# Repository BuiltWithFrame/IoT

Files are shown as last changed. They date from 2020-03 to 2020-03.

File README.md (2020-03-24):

# 👋 This is the Frame.IoT
The Frame.IoT is an Arduino-compatible board built for your Internet of Things projects and ships with the most popular components built-in — voted by the community. Now you can focus on building something awesome (instead of wiring up the basics).
# 💪 Everything you need
Powered by the ESP-32, the Frame.IoT is Wi-Fi and Bluetooth Low Energy (BLE) enabled. We packed it with all the plug-and-play utilities you've come to expect — USB-to-Serial converter, automatic bootloader reset and Lithium Ion/Polymer battery charging circuit. To make it project-ready, we gave the Frame.IoT a microSD card socket for all your data logging/storage needs, a super powerful digital audio amp to stream audio over the internet and blast notifications, a 16-pixel addressable RGB LED ring to light up your project, a toggle that lets you choose to power your peripherals over USB or battery, and an unencumbered momentary push-button to trigger any action you choose.
# 🙅‍♂️ No wasted pins
Not all projects are created equal. If your prototype doesn't need some of the components built-in to the Frame.IoT — no worries! Each component is connected via jumper pins. Simply remove the corresponding jumpers and you'll free up the I/O for anything you want!
# 🎗 The people who made this possible
This board was crowd-crafted and is in the process of being crowdfunded. [Click here to learn more, contribute, and get your name listed here.](https://www.kickstarter.com/projects/builtwithframe/frameiot-an-arduino-compatible-dev-kit-for-wi-fi-projects)
# ⚡️ Pinout
Frame.IoT Pinout

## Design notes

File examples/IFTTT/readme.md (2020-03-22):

# An Internet of Buttons
One of the most versatile uses of the Frame.IoT is leveraging the perfectly-positioned pushbutton (on digital pin 16) to trigger action in the world through platforms like IFTTT, Zapier, or your own native integrations with home automation platforms like Google Home, Apple Homekit, and Alexa.

Connect even the furriest of things to the internet

In this example, we're saving a lot of the coding headache by simply sending a `POST` request to an existing endpoint in IFTTT. IFTTT handles the rest and triggers a push notification to the registered device with the IFTTT app installed.

### Steps to recreate:
1. Fork/download the above `IFTTT.ino` sketch. Make sure you have all the libraries that are included or else the sketch won't compile
2. Change the `ssid` and `password` variables to match your network. (You can build upon this sketch to add your own networking handling and captive portals.)
3. Download the IFTTT mobile app for iOS/Android and create/login to a free account.
4. Create a new Applet and configure the trigger to be a Webhook. Note your `Event Name` and your `key`.
5. Going back to the sketch, replace the following line with your endpoint: `http.begin("https://maker.ifttt.com/trigger/{your_action}/with/key/{your_key}");`. It's safe to compile and upload this sketch to your Frame.IoT now.
6. In IFTTT, add an action step. We used the built-in notification system to trigger an alert but the possibilities are endless. You could even pass sensor data into the HTTP POST request and leverage the data on the action side.

Happy making!

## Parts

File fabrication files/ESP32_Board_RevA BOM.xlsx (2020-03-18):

ESP32_Board_RevA BOM | Created By: Junaid www.fiverr.com/junaid_ahmad92
Serial Number | Manufacturer | Manufacturer Part Number | Ref Designator | Qty | Description | Case | SMD, BGA, LCC (QFN) or TH | Top/ Bottom | Comments | Price/unint | Price/board | Internet Link
1 | Wurth Electronics Inc. | 61300211121 | J1, J2, J3, J4, J5, J6, J7, J8, J9, J10, J11, J12, J13 | 13 | CONN HEADER VERT 2POS 2.54MM |  |  |  |  | $0.13 | $1.69 | https://www.digikey.com/product-detail/en/wurth-electronics-inc/61300211121/732-5315-ND/4846823
2 | Harwin Inc. | M20-9991245 | J15 | 1 | CONN HEADER VERT 12POS 2.54MM |  |  |  |  | $0.46 | $0.46 | https://www.digikey.com/product-detail/en/harwin-inc/M20-9991245/952-3302-ND/3921252
3 | Harwin Inc. | M20-9991645 | J16 | 1 | CONN HEADER VERT 16POS 2.54MM |  |  |  |  | $0.60 | $0.60 | https://www.digikey.com/product-detail/en/harwin-inc/M20-9991645/952-3304-ND/3921260
4 | Phoenix Contact | 1984617 | SPKR1 | 1 | TERM BLK 2POS SIDE ENT 3.5MM PCB |  |  |  |  | $0.48 | $0.48 | https://www.digikey.com/product-detail/en/phoenix-contact/1984617/277-1721-ND/950849
5 | Samsung Electro-Mechanics | CL10B104KB8NNNC | C5, C10, C14, C15, C16, C17, C18 | 7 | CAP CER 0.1UF 50V X7R 0603 |  |  |  |  | $0.10 | $0.70 | https://www.digikey.com/product-detail/en/samsung-electro-mechanics/CL10B104KB8NNNC/1276-1000-1-ND/3889086
6 | Yageo | RC0603FR-07100KL | R1, R3, R7, R12, R9 | 5 | RES SMD 100K OHM 1% 1/10W 0603 |  |  |  |  | $0.10 | $0.50 | https://www.digikey.com/product-detail/en/yageo/RC0603FR-07100KL/311-100KHRCT-ND/729836
7 | Amphenol ICC (FCI) | 10118194-0001LF | J14 | 1 | CONN RCPT USB2.0 MICRO B SMD R/A |  |  |  |  | $0.42 | $0.70 | https://www.digikey.com/product-detail/en/amphenol-icc-fci/10118194-0001LF/609-4618-1-ND/2785382
8 | Yageo | YC164-JR-0710KL | R13 | 1 | RES ARRAY 4 RES 10K OHM 1206 |  |  |  |  | $0.11 | $0.11 | https://www.digikey.com/product-detail/en/yageo/YC164-JR-0710KL/YC164J-10KCT-ND/1005702
9 | KEMET | C0805C106K8PACTU | C1, C2, C3, C6, C8 | 5 | CAP CER 10UF 10V X5R 0805 |  |  |  |  | $0.16 | $0.80 | https://www.digikey.com/product-detail/en/kemet/C0805C106K8PACTU/399-4925-1-ND/1090920
10 | Yageo | RC0603FR-071KL | R2, R5 | 2 | RES SMD 1K OHM 1% 1/10W 0603 |  |  |  |  | $0.10 | $0.20 | https://www.digikey.com/product-detail/en/yageo/RC0603FR-071KL/311-1.00KHRCT-ND/729790
11 | Yageo | RC0603FR-071ML | R6 | 1 | RES SMD 1M OHM 1% 1/10W 0603 |  |  |  |  | $0.10 | $0.10 | https://www.digikey.com/product-detail/en/yageo/RC0603FR-071ML/311-1.00MHRCT-ND/729791
12 | Samsung Electro-Mechanics | CL10A105KA8NNNC | C4, C7 | 2 | CAP CER 1UF 25V X5R 0603 |  |  |  |  | $0.10 | $0.20 | https://www.digikey.com/product-detail/en/samsung-electro-mechanics/CL10A105KA8NNNC/1276-1102-1-ND/3889188
13 | Samsung Electro-Mechanics | CL10B221KB8NNNC | C12, C13 | 2 | CAP CER 220PF 50V X7R 0603 |  |  |  |  | $0.10 | $0.20 | https://www.digikey.com/product-detail/en/samsung-electro-mechanics/CL10B221KB8NNNC/1276-1145-1-ND/3889231
14 | Yageo | RC0603FR-074K7L | R4 | 1 | RES SMD 4.7K OHM 1% 1/10W 0603 |  |  |  |  | $0.10 | $0.10 | https://www.digikey.com/product-detail/en/yageo/RC0603FR-074K7L/311-4.70KHRCT-ND/730159
15 | Nexperia USA Inc. | 74HC4050D,653 | IC2 | 1 | IC BUFFER NON-INVERT 6V 16SO |  |  |  |  | $0.44 | $0.44 | https://www.digikey.com/product-detail/en/nexperia-usa-inc/74HC4050D653/1727-6331-1-ND/2762840
16 | Yageo | RC0603FR-07470RL | R8 | 1 | RES SMD 470 OHM 1% 1/10W 0603 |  |  |  |  | $0.10 | $0.10 | https://www.digikey.com/product-detail/en/yageo/RC0603FR-07470RL/311-470HRCT-ND/730203
17 | Diodes Incorporated | AP2112K-3.3TRG1 | U2 | 1 | IC REG LINEAR 3.3V 600MA SOT25 |  |  |  |  | $0.49 | $0.49 | https://www.digikey.com/product-detail/en/diodes-incorporated/AP2112K-3.3TRG1/AP2112K-3.3TRG1DICT-ND/4505257
18 | Silicon Labs | CP2104-F03-GMR | IC1 | 1 | IC SGL USB-TO-UART BRIDGE 24QFN |  |  |  |  | $1.65 | $1.65 | https://www.digikey.com/product-detail/en/silicon-labs/CP2104-F03-GMR/336-4146-1-ND/7650425
19 | Diodes Incorporated | DMG3415U-7 | Q3 | 1 | MOSFET P-CH 20V 4A SOT-23 |  |  |  |  | $0.42 | $0.42 | https://www.digikey.com/product-detail/en/diodes-incorporated/DMG3415U-7/DMG3415UDICT-ND/2052799
20 | E-Switch | EG1213 | S1 | 1 | SWITCH SLIDE SPDT 200MA 30V |  |  |  |  | $0.60 | $0.60 | https://www.digikey.com/products/en?keywords=EG1213
21 | Espressif Systems | ESP32-WROOM-32 | X5 | 1 | SMD MODULE, ESP32-D0WDQ6, 32MBIT |  |  |  |  | $3.80 | $3.80 | https://www.digikey.com/product-detail/en/espressif-systems/ESP32-WROOM-32/1904-1010-1-ND/8544305
22 | Taiyo Yuden | BKP2125HS600-T | FB1, FB2 | 2 | FERRITE BEAD 60 OHM 0805 1LN |  |  |  |  | $0.10 | $0.20 | https://www.digikey.com/product-detail/en/taiyo-yuden/BKP2125HS600-T/587-1932-6-ND/1465549
23 | JST Sales America Inc. | S2B-PH-SM4-TB(LF)(SN) | X2 | 1 | CONN HEADER SMD R/A 2POS 2MM |  |  |  |  | $0.58 | $0.58 | https://www.digikey.com/product-detail/en/jst-sales-america-inc/S2B-PH-SM4-TB-LF-SN/455-1749-1-ND/926846
24 | C&K | KMR231NG LFS | SW2 | 1 | SWITCH TACTILE SPST-NO 0.05A 32V |  |  |  |  | $0.52 | $0.52 | https://www.digikey.com/product-detail/en/c-k/KMR231NG-LFS/CKN10246CT-ND/2176497
25 | Maxim Integrated | MAX98357AETE+T | U1 | 1 | IC AMP CLASS D MONO 3.2W 16TQFN |  |  |  |  | $2.40 | $2.40 | https://www.digikey.com/product-detail/en/maxim-integrated/MAX98357AETE-T/MAX98357AETE-TCT-ND/7603777
26 | ON Semiconductor | MBR120VLSFT1G | D4 | 1 | DIODE SCHOTTKY 20V 1A SOD123FL |  |  |  |  | $0.45 | $0.45 | https://www.digikey.com/product-detail/en/on-semiconductor/MBR120VLSFT1G/MBR120VLSFT1GOSCT-ND/893874
27 | Microchip Technology | MCP73831T-2ACI/OT | U3 | 1 | IC CONTROLLR LI-ION 4.2V SOT23-5 |  |  |  |  | $0.56 | $0.56 | https://www.digikey.com/product-detail/en/microchip-technology/MCP73831T-2ACI-OT/MCP73831T-2ACI-OTCT-ND/1979802
28 | Amphenol ICC (Commercial Products) | 114-00841-68 | J17 | 1 | CONN MICRO SD CARD PUSH-PULL R/A |  |  |  |  | $1.13 | $1.13 | https://www.digikey.com/product-detail/en/amphenol-icc-commercial-products/114-00841-68/114-00841-68-1-ND/2187101
29 | C&K | PTS526 SKG15 SMTR2 LFS | S2 | 1 | TACT 5.2 X 5.2, 1.5 MM H, 260GF, |  |  |  |  | $0.10 | $0.10 | https://www.digikey.com/product-detail/en/c-k/PTS526-SKG15-SMTR2-LFS/CKN12223-1-ND/10056636
30 | Lite-On Inc. | LTST-C171KRKT | CHG, ACT | 2 | LED RED CLEAR SMD |  |  |  |  | $0.29 | $0.58 | https://www.digikey.com/product-detail/en/lite-on-inc/LTST-C171KRKT/160-1427-1-ND/386800
31 | Adafruit Industries LLC | 1655 | LED1, LED2, LED3, LED4, LED5, LED6, LED7, LED8, LED9, LED10, LED11, LED12, LED13, LED14, LED15, LED16 | 16 | ADDRESS LED DISC SERIAL RGB 1=10 |  |  |  | SK6812 in 5050 will work too | $0.45 | $7.20 | https://www.digikey.com/product-detail/en/adafruit-industries-llc/1655/1528-1104-ND/5154679
32 | Diodes Incorporated | MMBT2222A-7-F | Q1, Q2 | 2 | TRANS NPN 40V 0.6A SMD SOT23-3 |  |  |  |  | $0.13 | $0.26 | https://www.digikey.com/product-detail/en/diodes-incorporated/MMBT2222A-7-F/MMBT2222A-FDICT-ND/815723

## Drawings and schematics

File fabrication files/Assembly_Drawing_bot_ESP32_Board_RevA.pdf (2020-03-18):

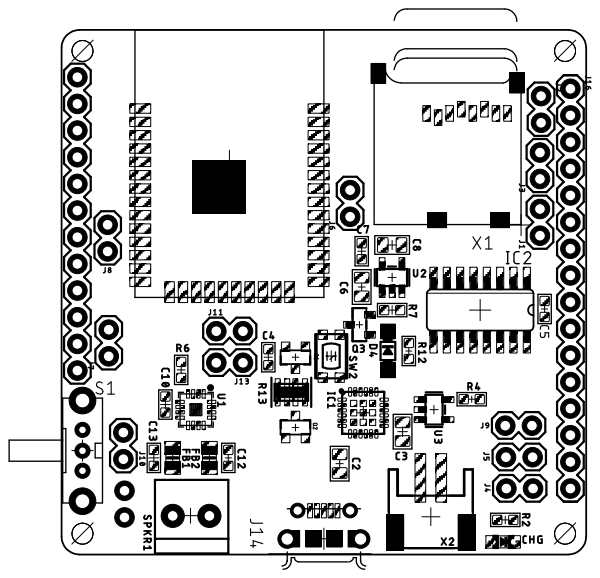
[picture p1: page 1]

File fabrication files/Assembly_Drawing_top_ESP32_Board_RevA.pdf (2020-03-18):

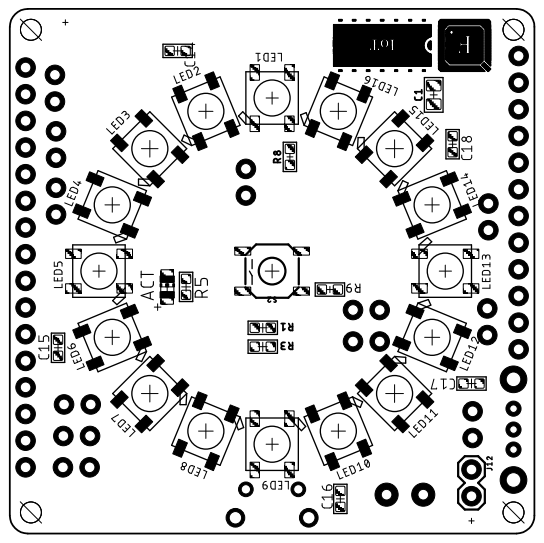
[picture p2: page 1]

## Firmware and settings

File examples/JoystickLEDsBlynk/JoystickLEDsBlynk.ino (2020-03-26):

#include <WiFi.h>
#include <WiFiClient.h>
#include <BlynkSimpleEsp32.h>
#include <NeoPixelBus.h>
#define BLYNK_PRINT Serial

char auth[] = "#########################";
char ssid[] = "########";
char pass[] = "########";
const uint16_t PixelCount = 16;
const uint16_t PixelPin = 32;
int xCenter, yCenter, xReading, yReading, pixelNumber, oldPixelNumber;

NeoPixelBus<NeoGrbFeature, Neo800KbpsMethod> strip(PixelCount, PixelPin);

void setup() {
  xCenter = 512;
  yCenter = 512;
  xReading = 512;
  yReading = 512;
  pixelNumber = -1;
  oldPixelNumber = pixelNumber;
  Serial.begin(115200);
  Blynk.begin(auth, ssid, pass);
  strip.Begin();
  strip.Show();
}

void loop() {
  Blynk.run();
  strip.Show();
}

BLYNK_WRITE(V0) {
  xReading = param[0].asInt();
  yReading = param[1].asInt();
  Serial.print(xReading);
  Serial.print(", ");
  Serial.println(yReading);
  double joystickRadians;
  double joystickDegrees;
  joystickDegrees = getDegrees(xReading, yReading);
  pixelNumber = map(joystickDegrees, 0, 330, 0, 15);
  pixelNumber = constrain(pixelNumber, 0, 15);
  if (oldPixelNumber != pixelNumber) {
    strip.SetPixelColor(pixelNumber, RgbColor(50, 50, 50));
    strip.SetPixelColor(oldPixelNumber, RgbColor(0, 0, 0));
  }
  if (xReading == 512 && yReading == 512) {
    strip.SetPixelColor(pixelNumber, RgbColor(0, 0, 0));
    strip.SetPixelColor(oldPixelNumber, RgbColor(0, 0, 0));
  }
  oldPixelNumber = pixelNumber;
}

double getDegrees(int x, int y) {
  int xCalibrated = x - xCenter;
  int yCalibrated = y - yCenter;
  xCalibrated = -xCalibrated;
  yCalibrated = -yCalibrated;
  double calculation = atan2(yCalibrated, xCalibrated) * 180 / PI;
  if (calculation < 0) {
    calculation += 360;
  }
  return calculation;
}

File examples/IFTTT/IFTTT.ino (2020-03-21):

#include <WiFi.h>
#include <HTTPClient.h>
#include <NeoPixelBus.h>
#include <NeoPixelAnimator.h>

const char* ssid ="********";
const char* password = "********";
const int buttonPin = 16;
int buttonPressDuration;
const int PixelCount = 16;
const int PixelPin = 32;
const int AnimCount = 1;
const int TailLength = 6;
const float MaxLightness = 0.2f;

NeoGamma<NeoGammaTableMethod> colorGamma;
NeoPixelBus<NeoGrbFeature, Neo800KbpsMethod> strip(PixelCount, PixelPin);
NeoPixelAnimator animations(AnimCount);


void setup() {
  Serial.begin(115200);
  pinMode(buttonPin, INPUT_PULLUP);
  strip.Begin();
  WiFi.begin(ssid, password); 
  while (WiFi.status() != WL_CONNECTED) {
    delay(1000);
    Serial.println("Connecting to WiFi..");
  }
  Serial.println("Connected to the WiFi network");
}

void loop() {
  animations.UpdateAnimations();
  strip.Show();
  if (is_button_pressed(100000)) {
    DrawTailPixels();
    animations.StartAnimation(0, 100, LoopAnimUpdate); 
    if(WiFi.status()== WL_CONNECTED) {
      HTTPClient http;   
      http.begin("https://maker.ifttt.com/trigger/{your_action}/with/key/{your_key}");
      http.addHeader("Content-Type", "text/plain");
      int httpResponseCode = http.POST("Test");
      if (httpResponseCode>0) {
        String response = http.getString();
        Serial.println(httpResponseCode);
        Serial.println(response);
      } else {
        Serial.print("Error on sending POST: ");
        Serial.println(httpResponseCode);
      }
      http.end();
    } else {
      Serial.println("Error in WiFi connection");   
    }
  }
}

bool is_button_pressed(int buttonPressRequirement) {
  if (digitalRead(buttonPin) == LOW) {
    buttonPressDuration++;
    if (buttonPressDuration >= buttonPressRequirement) {
      buttonPressDuration = 0;
      Serial.println("Furry paw detected!");
      return true;
    } else {
      return false;
    }
  } else {
    buttonPressDuration = 0;
    return false;  
  }
}

void LoopAnimUpdate(const AnimationParam& param) {
  if (param.state == AnimationState_Completed){
    animations.RestartAnimation(param.index);
    strip.RotateRight(1);
  }
}

void DrawTailPixels() {
  float hue = 100 / 360.0f;
  for (uint16_t index = 0; index < strip.PixelCount() && index <= TailLength; index++) {
    float lightness = index * MaxLightness / TailLength;
    RgbColor color = HslColor(hue, 1.0f, lightness);
    strip.SetPixelColor(index, colorGamma.Correct(color));
  }
}

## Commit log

2019-12-24 Added board schematic
2020-03-18 Added fabrication files
    [ESP32_Board_RevA BOM.xlsx, ESP32_Board_RevA_centroid.csv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]
